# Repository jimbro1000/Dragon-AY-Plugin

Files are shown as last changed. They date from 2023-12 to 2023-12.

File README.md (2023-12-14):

# AY(ish) Plugin For Dragon32 Rev 3 #

This repository contains the design for an emulated AY8910/2/3 
plugin board to fit the Dragon32 Rev3 boards.

The design is based on the avr-ay designs using an Atmega MCU

The design does not support the PIO capabilities of the
original AY8910/2, providing only the sound generation

The footprint is a significant departure using a largish
plcc style footprint but thanks to a lack of support in
KiCad this has come out larger than intended

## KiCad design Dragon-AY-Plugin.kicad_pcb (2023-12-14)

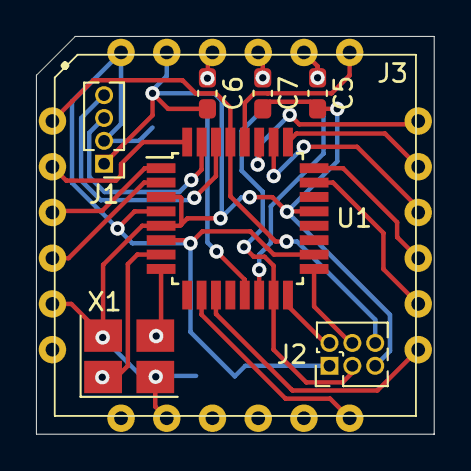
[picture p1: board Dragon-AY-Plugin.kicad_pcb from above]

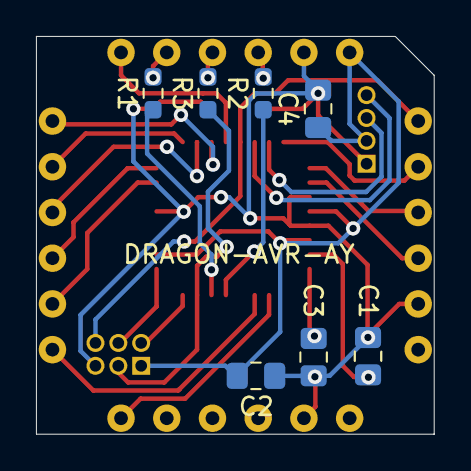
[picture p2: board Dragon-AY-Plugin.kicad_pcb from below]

Board: 2 copper layers, 22.1 x 22.1 mm, 15 parts (7 on the bottom side), 26 nets.

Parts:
C1, C3: 18pF; C_0805_2012Metric_Pad1.18x1.45mm_HandSolder
C2, C4: 100nF; C_0805_2012Metric_Pad1.18x1.45mm_HandSolder
C5, C6, C7: 2.2nF; C_0603_1608Metric_Pad1.08x0.95mm_HandSolder
J1: UART; PinHeader_1x04_P1.27mm_Vertical
J2: ICSP; PinHeader_2x03_P1.27mm_Vertical
J3: Conn_01x24; AY-QTHT
R1, R2, R3: 3.6K; R_0603_1608Metric_Pad0.98x0.95mm_HandSolder
U1: ATmega48PA-A; TQFP-32_7x7mm_P0.8mm
X1: 27MHz; Crystal_SMD_3225-4Pin_3.2x2.5mm_HandSoldering

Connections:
+5V: C2.1, C4.1, J1.2, J2.1, J3.1, U1.4 (VCC), U1.6 (VCC), U1.18 (AVCC)
BC1: J3.23, U1.32 (PD2)
BDIR: J3.22, U1.1 (PD3)
CLOCK: J3.21, U1.2 (PD4)
D0: J3.11, U1.23 (PC0)
D1: J3.10, U1.24 (PC1)
D2: J3.8, U1.25 (PC2)
D3: J3.9, U1.26 (PC3)
D4: J3.7, U1.27 (PC4)
D5: J3.6, U1.28 (PC5)
D6: J3.13, U1.10 (PD6)
D7: J3.12, U1.11 (PD7)
GND: C1.2, C2.2, C3.2, C4.2, C5.2, C6.2, C7.2, J1.1, J2.5, J3.2, J3.17, J3.20, U1.3 (GND), U1.5 (GND), U1.21 (GND), X1.2, X1.4
MISO: J2.2, U1.16 (PB4)
MOSI: J2.3, R3.1, U1.15 (PB3)
OUT_A: C6.1, J3.3, R2.2
OUT_B: C7.1, J3.4, R3.2
OUT_C: C5.1, J3.5, R1.2
PWM_A: R2.1, U1.13 (PB1)
PWM_C: R1.1, U1.14 (PB2)
RX: J1.4, U1.30 (PD0)
SCK: J2.4, U1.17 (PB5)
TX: J1.3, U1.31 (PD1)
XTAL1: C1.1, U1.7 (XTAL1/PB6), X1.1
XTAL2: C3.1, U1.8 (XTAL2/PB7), X1.3
~RES: J2.6, J3.24, U1.29 (~RESET/PC6)
